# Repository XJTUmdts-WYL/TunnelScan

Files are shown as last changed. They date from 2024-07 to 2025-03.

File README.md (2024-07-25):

# TunnelScan: A Novel Tunnel Surface Defect Detection Model

## Overview

TunnelScan is a state-of-the-art model designed for detecting surface defects in tunnel structures. The model leverages advanced components such as the C2fGLU layer based on the GLUBottleneck module and includes additional upsampling and concatenation steps. These enhancements allow for superior feature representation and the construction of a robust feature pyramid, enabling the model to effectively capture fine and small-scale features. Furthermore, TunnelScan employs a sophisticated detection head and introduces an additional feature map level for improved accuracy.

## Features

- **C2fGLU Layer**: Based on the GLUBottleneck module, enhances feature extraction.
- **Feature Pyramid**: Incorporates additional upsampling and concatenation steps for robust multi-scale feature representation.
- **Advanced Detection Head**: Utilizes a more sophisticated detection head for better precision.
- **Additional Feature Map Level**: Captures fine and small-scale features more effectively.

## The code will be made public after the article is accepted

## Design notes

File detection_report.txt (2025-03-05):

======== 无人机视觉检测报告 ========

分析时间: 2024-10-21 11:03:33
触发警报次数: 6

目标类别分布:
- leakage: 7次
- bolt: 18次
- spalling: 12次
- crack: 15次

警报事件时间线:
[2024-10-21 11:02:19] leakage (200.0x405.4px) @ (x=0.55, y=7.7, z=2.261)
[2024-10-21 11:02:31] spalling (179.3x360.4px) @ (x=0.12, y=13.9, z=2.365)
[2024-10-21 11:02:44] leakage (672.1x1052.3px) @ (x=-0.03, y=14.5, z=2.513)
[2024-10-21 11:02:54] crack (177.0x464.1px) @ (x=-0.13, y=16.6, z=2.87)
[2024-10-21 11:03:20] crack (104.3x327.1px) @ (x=0.06, y=22.4, z=2.354)
[2024-10-21 11:03:25] leakage (210.0x146.1px) @ (x=0.09, y=24.5, z=2.353)

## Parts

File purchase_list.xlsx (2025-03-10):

类目 | 型号 | 数量 | 单价 | 总价 | 购买链接
动力套装
机架 | LJI-X400 Pro | 1 | 288 | 288 | https://item.taobao.com/item.htm?_u=d3ovgp2s356d&id=661322510447&sku_properties=31309:16741168228
无刷电机 | T-Motor F100 KV1100 | 4 | 229 | 916 | https://item.taobao.com/item.htm?_u=d3ovgp2s37a9&id=666218265469&sku_properties=31309:18046510136
飞控+电调 | H7 MINI + F4 4IN1 MINI 50A ESC | 1 | 916 | 916 | https://item.taobao.com/item.htm?_u=d3ovgp2s075e&id=695089334583&skuId=4934678877288
桨叶 | HQ 7040-3 | 1 | 15 | 15 | https://item.taobao.com/item.htm?_u=t3ovgp2s460a&id=671633881954&skuId=5010241515719
接收机 | 乐迪 R12DSM | 1 | 93 | 93 | https://item.taobao.com/item.htm?spm=a1z09.2.0.0.2abd2e8da0sHzh&id=541658831753&_u=l32egecq5116
遥控器 | 乐迪 AT9S PRO 左手不回中 | 1 | 545 | 545 | https://item.taobao.com/item.htm?_u=t3ovgp2s8571&id=620560690486&skuId=4648673175694
电池 | 格氏 4000mAh 6S | 1 | 488 | 488 | https://detail.tmall.com/item.htm?_u=t3ovgp2sa7dc&id=14832015119&spm=a1z09.2.0.0.32aa2e8df64WUL
穿越机脚垫 | 30*15*10mm | 1 | 16.99 | 16.99 | https://item.taobao.com/item.htm?_u=t3ovgp2se7b0&id=562158533089&skuId=3961675618573
 |  |  | 动力套成本 | 3277.99
感知模块配件
DC供电线 | XT60 | 1 | 13 | 13 | https://item.taobao.com/item.htm?spm=a1z09.2.0.0.773d2e8despLGo&id=613472402389&_u=g2epqo5e38f7
飞控连接线 | 双左弯0.15m | 1 | 9.5 | 9.5 | https://detail.tmall.com/item.htm?id=43144333772&_u=i32egecqf5d3&skuId=4498792030458
TYPEC连接线 | 15cm | 1 | 22.9 | 22.9 | https://detail.tmall.com/item.htm?id=617461584216&spm=a1z09.2.0.0.2abd2e8da0sHzh&_u=l32egecq0e19
HDMI欺骗器 |  | 1 | 3 | 3 | https://item.taobao.com/item.htm?id=600829968368&ali_trackid=1_b8192277632fc8796a134ac616741b67
DC-DC稳压模块 | LTC3780 | 1 | 38 | 38 | https://item.taobao.com/item.htm?_u=p3ovgp2s988d&id=537511849240&spm=a1z09.2.0.0.19c62e8dwykGML
 |  |  | 感知模块配件成本 | 48.4
感知模块核心
机载电脑 | Intel NUC 猛虎峡谷 准系统 i5 薄款 | 1 | 2590 | 2590 | https://item.taobao.com/item.htm?id=638758423001&ns=1&abbucket=3
 | 三星 DDR4内存条 8G 3200hz | 1 | 229 | 229 | https://detail.tmall.com/item.htm?id=541378489978&spm=a1z09.2.0.0.ea4d2e8dwctqDn&_u=t2epqo5eaa9f
 | 影驰黑将 250G M.2固态硬盘 | 1 | 234 | 234 | https://detail.tmall.com/item.htm?id=541378489978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
双目深度相机 | INTEL REALSENSE D435 | 1 | 2180 | 2180 | https://item.taobao.com/item.htm?spm=a1z10.1-c.w4004-8474743471.36.1f164e1fL0mvDM&id=670494420704
激光雷达 | Livox Mid-360 | 1 | 3999 | 3999 | https://store.dji.com/cn/product/livox-mid-360?vid=130851
 |  |  | 感知模块核心成本 | 9232
3D打印零件
上板 | 上板 | 1 | Nan | Nan
脚架 | 脚架 | 1 | Nan | Nan
感知模块支架 | 感知模块支架 | 1 | Nan | Nan
 |  |  | 3D打印成本 | Nan
配件
硅胶线 | 20,18,16AWG | 若干 | Nan | Nan | https://item.taobao.com/item.htm?id=631990884181&ns=1&abbucket=3
BB响 |  | 1 | Nan | Nan | https://item.taobao.com/item.htm?id=13954041762&ns=1&abbucket=3
硅胶杜邦线 | 10cm,15cm，公对母 | 若干 | Nan | Nan | https://item.taobao.com/item.htm?id=567943637652&ali_trackid=1_82cb0cae98e77d6ab8f389660ffac1cf
3.5mm香蕉头 公母头 |  | 12 | Nan | Nan
XT60公、母头 |  | 1 | Nan | Nan
双通铝柱 | M3*25 | 4 | Nan | Nan | https://item.taobao.com/item.htm?id=603331087035&ns=1&abbucket=13
3M双面胶 | 20mm*3m | 1 | Nan | Nan | https://detail.tmall.com/item.htm?id=653733592411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
螺丝 | M3*6mm M3*8mm 杯头 | 若干 | Nan | Nan | https://detail.tmall.com/item.htm?id=624811454452&_u=i32egecq19dc&skuId=4601948603338
 |  |  | 配件成本 | Nan
工具
烙铁 | AT937标配 | 143 | 1 | 143 | https://item.taobao.com/item.htm?id=7800035658&ns=1&abbucket=14
烙铁头 | 900M-1.6K | 11 | 1 | 11 | https://item.taobao.com/item.htm?spm=a1z10.3-c-s.w4002-23344838098.27.754f1004qeCAY6&id=579728085148
海绵 |  | 2 | 1 | 2 | https://item.taobao.com/item.htm?spm=a1z10.3-c-s.w4002-23344838098.9.6d6c1004U43LPK&id=7586598250
焊锡 | 0.5mm 500g | 76.67 | 1 | 76.67 | https://detail.tmall.com/item.htm?spm=a230r.1.14.11.552520bejLfPiP&id=43741015860&ns=1&abbucket=14
夹持台 | 褐色 | 75 | 1 | 75 | https://item.taobao.com/item.htm?id=613902998667&ali_trackid=1_a8d9bfa88456e4bdeb5141959028dacf
扳手 |  | 11 | 1 | 11 | https://item.taobao.com/item.htm?id=610029436080&ns=1&abbucket=14
螺丝刀 | 2.0mm、2.5mm | 10.99 | 1 | 10.99 | https://detail.tmall.com/item.htm?id=572329178882&cm_id=140105335569ed55e27b&abbucket=14
万用表 |  | 49 | 1 | 49 | https://item.jd.com/100000287597.html
剪刀 | 3把中号 | 10.9 | 0.33 | 3.597 | https://item.jd.com/6020791.html
切割垫 | A3 | 19.9 | 1 | 19.9 | https://item.jd.com/100001317628.html
 |  |  | 工具成本 | 402.157

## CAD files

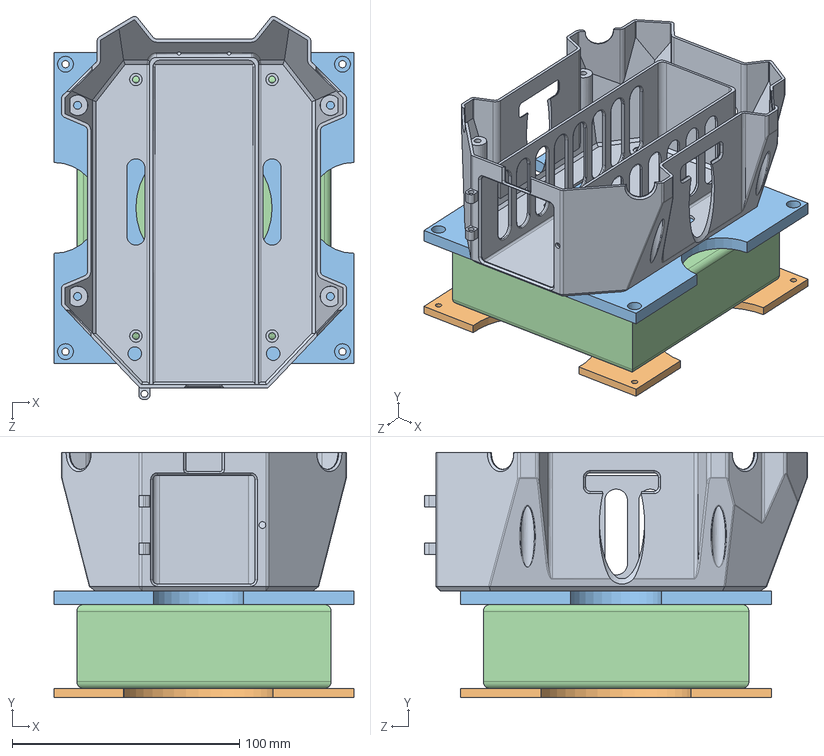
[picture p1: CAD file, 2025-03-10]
UAV3Dprint/装配体1.SLDASM
132.0 x 108.0 x 168.7 mm
底壳.stp
零件1
零件1 - 副本
电脑

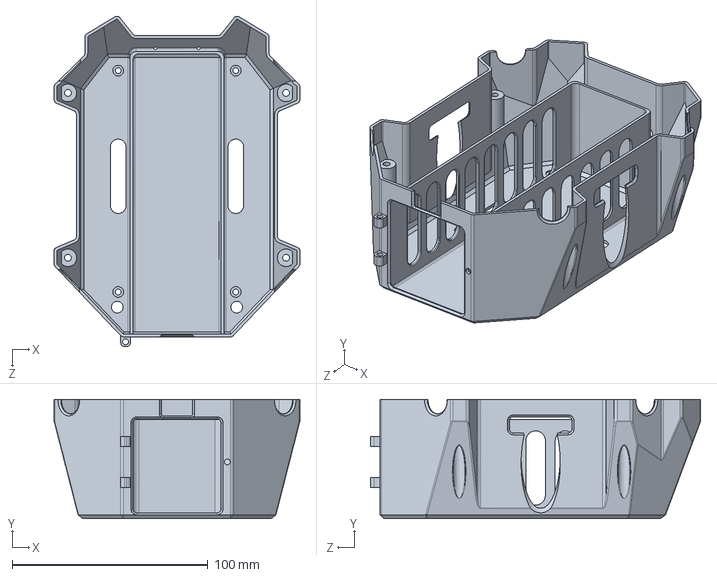
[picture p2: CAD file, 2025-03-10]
UAV3Dprint/底壳.stp.SLDPRT
125.6 x 61.0 x 168.7 mm

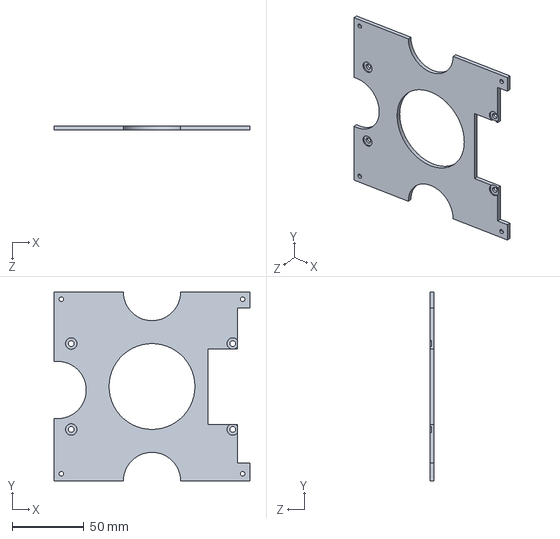
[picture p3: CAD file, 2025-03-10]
UAV3Dprint/支架上.STEP
137.0 x 132.0 x 3.00 mm

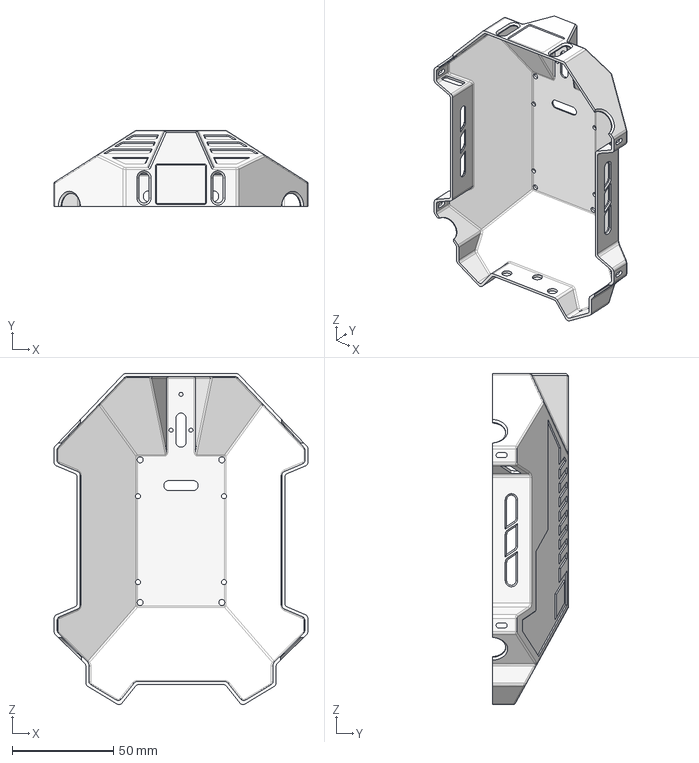
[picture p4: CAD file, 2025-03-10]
UAV3Dprint/顶壳.stp
125.6 x 37.5 x 163.7 mm

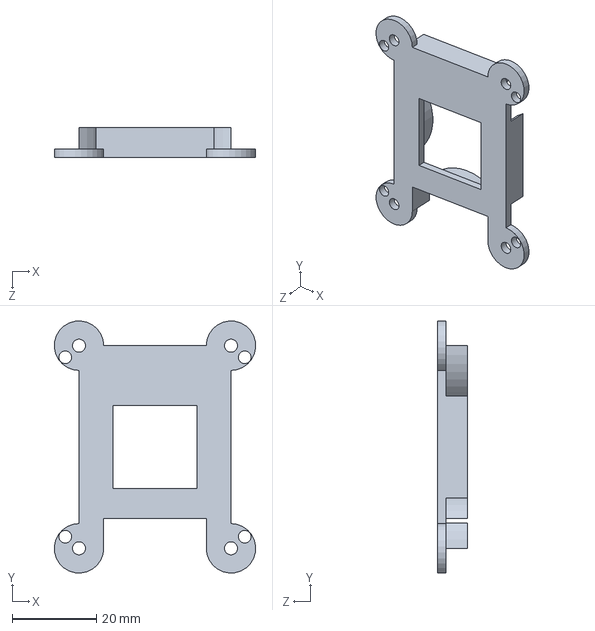
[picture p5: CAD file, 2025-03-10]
UAV3Dprint/零件12.SLDPRT
47.7 x 59.7 x 7.00 mm

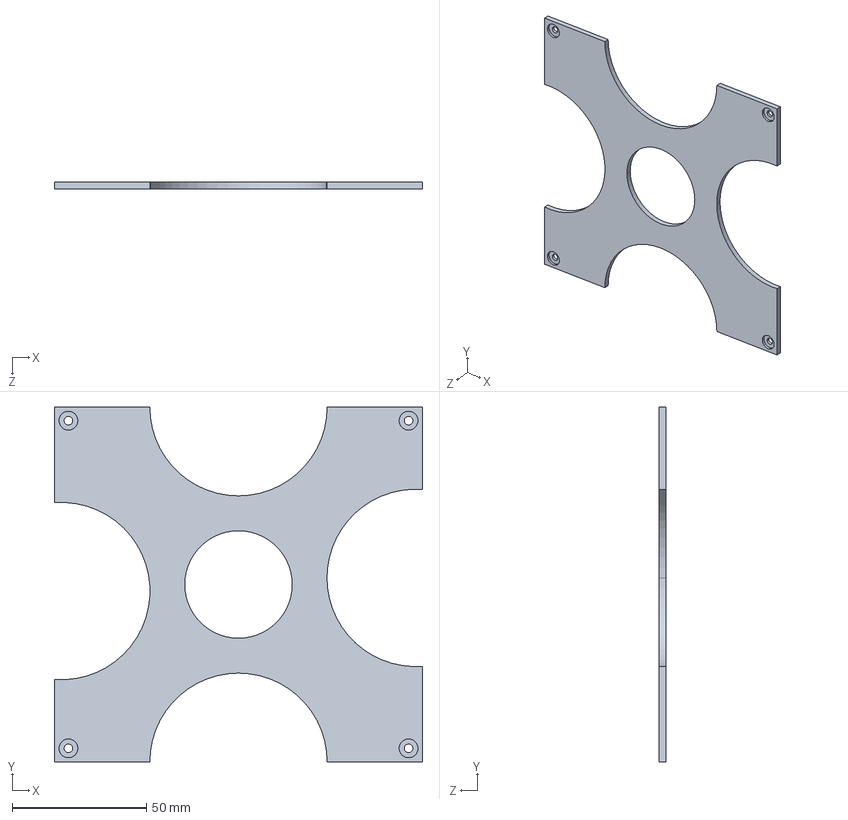
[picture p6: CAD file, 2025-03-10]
UAV3Dprint/支架中下.STEP
137.0 x 132.0 x 2.50 mm

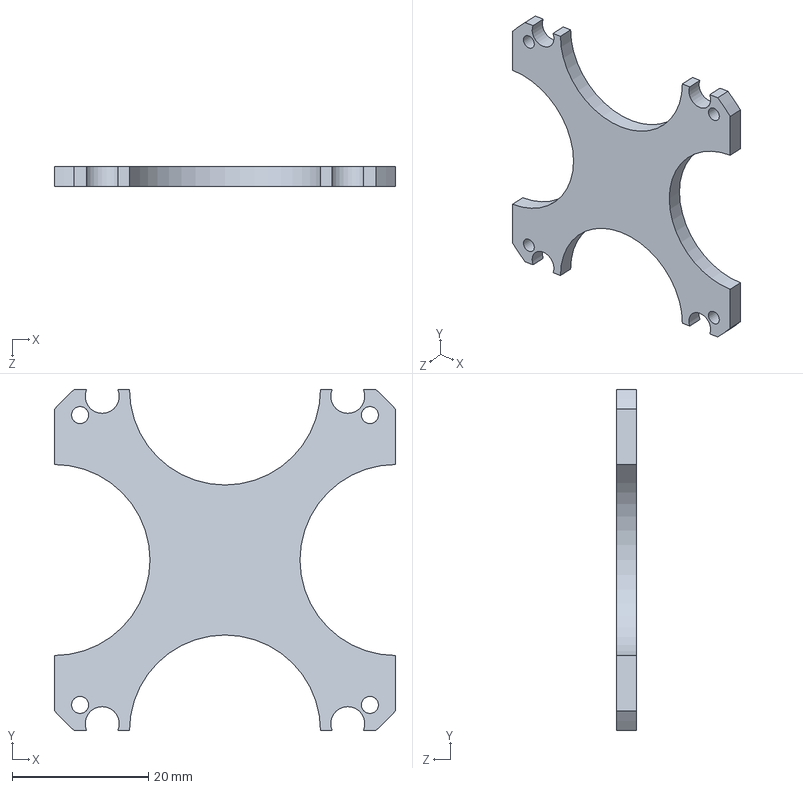
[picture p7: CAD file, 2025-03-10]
UAV3Dprint/零件11.SLDPRT
50.0 x 50.0 x 3.00 mm

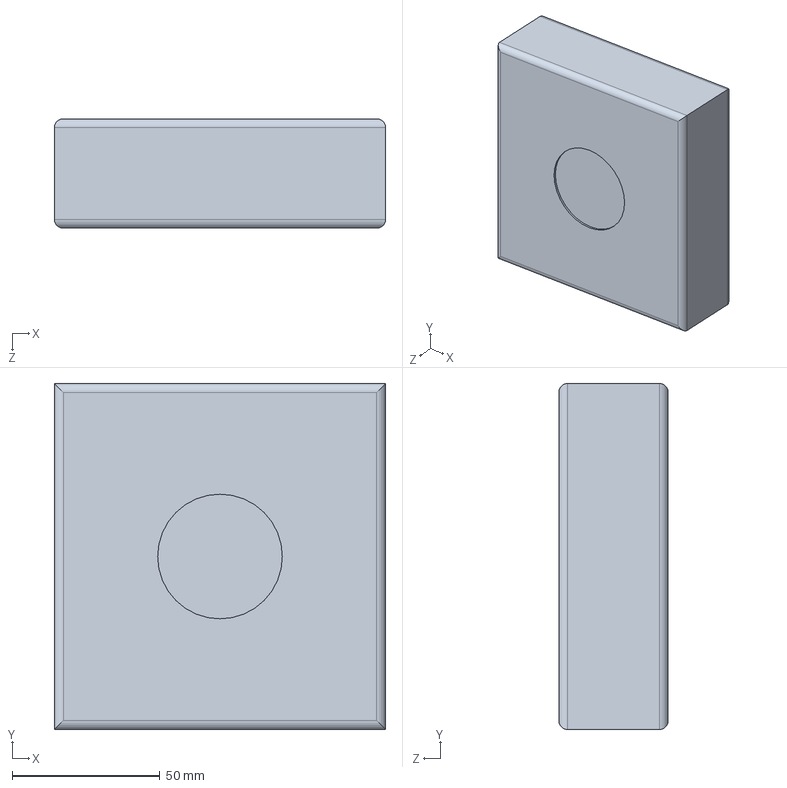
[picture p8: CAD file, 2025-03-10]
UAV3Dprint/电脑.SLDPRT
112.0 x 117.0 x 37.0 mm

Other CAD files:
UAV3Dprint/底壳.stp
UAV3Dprint/支架上.SLDPRT
UAV3Dprint/支架上.STL
UAV3Dprint/支架中下.SLDPRT
UAV3Dprint/支架中下.STL
UAV3Dprint/顶壳.SLDPRT

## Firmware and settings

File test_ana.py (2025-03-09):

import cv2
from ultralytics import YOLO
import time
import threading
from pymavlink import mavutil
from queue import Queue


model = YOLO(r"runs\tunnelsacn.pt")

# 初始化摄像头
cap = cv2.VideoCapture(0)  

# MAVLink连接配置
MAVLINK_CONNECTION = 'udp:localhost' 
position_queue = Queue(maxsize=1)  

# 检测参数配置
min_width = 300
min_height = 300
log_file = 'detection_log.txt'
report_file = 'detection_report.txt'

# 状态跟踪变量
start_time = time.time()
total_detections = 0
alert_count = 0
max_width = 0
max_height = 0
class_counts = {}
alert_events = []

# 处理频率控制
PROCESS_FPS = 2  # 每秒处理帧数
frame_interval = 1.0 / PROCESS_FPS
last_process_time = time.time()

def mavlink_listener():
    """MAVLink位置监听线程"""
    mav = mavutil.mavlink_connection(MAVLINK_CONNECTION)
    
    print("等待MAVLink心跳...")
    mav.wait_heartbeat()
    print("MAVLink连接成功!")
    
    while True:
        try:
            msg = mav.recv_match(blocking=True, timeout=5)
            if not msg:
                continue
                
            if msg.get_type() == 'LOCAL_POSITION_NED':
                # 获取相对位置（相对于起飞点）
                position = (msg.x, msg.y, msg.z)
                # 更新位置队列（只保留最新位置）
                if position_queue.full():
                    position_queue.get()
                position_queue.put(position)
                
        except Exception as e:
            print(f"MAVLink错误: {str(e)}")
            break

def get_drone_position():
    """从队列获取最新无人机位置"""
    try:
        return position_queue.get_nowait()
    except:
        return (0.0, 0.0, 0.0)  # 默认位置

def write_log(data):
    """写入日志文件"""
    with open(log_file, 'a') as f:
        f.write(f"{time.strftime('%Y-%m-%d %H:%M:%S')} | {data}\n")

def generate_report():
    """生成检测报告"""
    with open(report_file, 'w') as f:
        f.write("======== 无人机视觉检测报告 ========\n\n")
        f.write(f"视频分析时间: {time.strftime('%Y-%m-%d %H:%M:%S')}\n")
        f.write(f"总检测次数: {total_detections}\n")
        f.write(f"触发警报次数: {alert_count}\n")
        f.write(f"最大检测尺寸: {max_width:.1f}x{max_height:.1f}px\n\n")

        f.write("目标类别分布:\n")
        for cls, count in class_counts.items():
            f.write(f"- {cls}: {count}次\n")

        f.write("\n警报事件时间线:\n")
        for event in alert_events:
            f.write(f"[{event['time']}] {event['class']} ({event['width']:.1f}x{event['height']:.1f}px) "
                    f"@ (x={event['position'][0]:.1f}, y={event['position'][1]:.1f}, z={event['position'][2]:.1f})\n")

# 启动MAVLink监听线程
mav_thread = threading.Thread(target=mavlink_listener, daemon=True)
mav_thread.start()

# 主循环
try:
    while cap.isOpened():
        # 读取摄像头帧
        ret, frame = cap.read()
        if not ret:
            print("摄像头读取失败")
            break

        # 控制处理频率
        current_time = time.time()
        if current_time - last_process_time < frame_interval:
            continue
            
        last_process_time = current_time

        # 执行目标检测
        results = model(frame)

        # 处理检测结果
        for result in results:
            for box in result.boxes:
                total_detections += 1
                cls_id = int(box.cls[0])
                cls_name = model.names[cls_id]
                xyxy = box.xyxy[0].tolist()
                width = xyxy[2] - xyxy[0]
                height = xyxy[3] - xyxy[1]

                # 更新统计数据
                class_counts[cls_name] = class_counts.get(cls_name, 0) + 1
                max_width = max(max_width, width)
                max_height = max(max_height, height)

                # 写入日志
                log_entry = f"{cls_name} ({width:.1f}x{height:.1f}px) @ [{xyxy[0]:.1f},{xyxy[1]:.1f}]"
                write_log(log_entry)

                # 触发警报检测
                if width > min_width and height > min_height:
                    alert_count += 1
                    position = get_drone_position()
                    alert_time = time.strftime('%Y-%m-%d %H:%M:%S')
                    alert_events.append({
                        'time': alert_time,
                        'class': cls_name,
                        'width': width,
                        'height': height,
                        'position': position
                    })
                    geo_log = f"ALERT: {cls_name} @ (x={position[0]:.1f}, y={position[1]:.1f}, z={position[2]:.1f})"
                    write_log(geo_log)
                    print(f"[警报] {geo_log}")

        # 显示实时画面（可选）
        cv2.imshow('Drone Detection', frame)
        if cv2.waitKey(1) & 0xFF == ord('q'):
            break

except KeyboardInterrupt:
    print("用户中断操作")

finally:
    # 释放资源
    cap.release()
    cv2.destroyAllWindows()
    generate_report()
    print("实时检测结束，检测报告已生成")
